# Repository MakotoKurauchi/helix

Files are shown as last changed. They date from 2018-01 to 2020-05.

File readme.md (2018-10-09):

# Helix

Helix

A compact split ortholinear keyboard.

## Documents

* Build Guide - [JP](/Doc/buildguide_jp.md), [EN](/Doc/buildguide_en.md)
* Firmware - [JP](/Doc/firmware_jp.md), [EN](/Doc/firmware_en.md)
* Usage - [JP](/Doc/usage_jp.md), [EN](/Doc/usage_en.md) 

## Tool & Data

* [PCB Data](/PCB)
* [Case Data](/Case)
* [Font Converter](/FontConverter)

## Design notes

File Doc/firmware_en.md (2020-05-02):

# Firmware

## To Simply Verify Function

It is possible to verify functionality without building using [QMK Toolbox](https://github.com/qmk/qmk_toolbox/releases).

Imgur

1. Verify that an atmega32u4 is detected
2. Download any of the firmwares below which suits the options selected, and open it in QMK Toolbox

- No options: [helix_rev2_default.hex](http://qmk.fm/compiled/helix_rev2_default.hex)
- 5-row OLED and backlight: [helix_rev2_default_oled_backlight.hex](https://raw.githubusercontent.com/MakotoKurauchi/helix/master/Hex/helix_rev2_default_oled_backlight.hex)
- 5-row OLED and underglow: [helix_rev2_default_oled_underglow.hex](https://raw.githubusercontent.com/MakotoKurauchi/helix/master/Hex/helix_rev2_default_oled_underglow.hex)
- 4-row OLED and backlight: [helix_rev2_default_4rows_oled_backlight.hex](https://raw.githubusercontent.com/MakotoKurauchi/helix/master/Hex/helix_rev2_default_4rows_oled_backlight.hex)
- 4-row OLED and underglow: [helix_rev2_default_4rows_oled_underglow.hex](https://raw.githubusercontent.com/MakotoKurauchi/helix/master/Hex/helix_rev2_default_4rows_oled_underglow.hex)
-
Imgur

1. Press the reset button on helix, and verify that it shows as "connected"
2. Immediately press flash

Imgur

If a message similar to this appears, flashing has succeeded.

Please verify that typing is possible using these firmwares.

To change the layout, use the build guide below.

## Setting up the build environment

Create the build environment according to the official guide of QMK.

https://docs.qmk.fm/#/newbs_getting_started

## Build and flash

Run the following at the root directory of the QMK folder:

    make helix:default

To flash at the same time, attach `:avrdude` to the command:

    make helix:default:avrdude

For flashing via GUI, use [QMK Toolbox](https://github.com/qmk/qmk_toolbox/releases) as described earlier.

Both halves must be flashed.

## Customize

Copy and rename the `default` folder in `/keyboards/helix/rev2/keymaps/`.
This new folder will be used from now on.

For building this new keymap, the following command will be used:

    make helix:<new keymap folder name>

## Editing the keymaps

The default keymap is stored in keymap.c. It can be edited to modify the keymap freely.

Please see [this page](https://docs.qmk.fm/#/keycodes) for a keycode reference.

Imgur

## Making the keymap 4 rows

Within the folder, change the field HELIX_ROWS rules.mk from 5 to 4.

    HELIX_ROWS = 4

## Enable RGB backlighting

In the same file, change the LED_BACK_ENABLE from no to yes.

    LED_BACK_ENABLE = yes

##  Enable RGB underglow

Again in the same file, change LED_UNDERGLOW_ENABLE from no to yes.

    LED_UNDERGLOW_ENABLE = yes

## Enable OLED display

Again in the same file, change OLED_ENABLE from no to yes.

    OLED_ENABLE = yes

### Edit font data
The font data is stored in helix/common/glcdfont.c.
This data can be edited in the following ways for modifying OLED content.

#### Using the web tool

The web tool created by [@teri_yakichan](https://twitter.com/teri_yakichan) can be used to modify the file easily.

[Helix Font Editor](https://helixfonteditor.netlify.com/)

#### Using an image editor

To use an image editor, do the following to convert text to image.

1. Take the image data from glcdfont.c and move it to a text file.
0x00, 0x00 ... 0x00
2. Use the script to convert to image
3. Edit the image
4. Use the script to convert back to text
5. Insert to glcdfont.c

An example image being edited:

Font

The following script is used for conversion.
https://github.com/MakotoKurauchi/helix/tree/master/FontConverter

Converting text to image

    $ python3 hex2img.py inHex.txt outImage

Converting image to text

    $ python3 img2hex.py inImage.bmp > outHex.txt

### Creating a font data specific to the keymap

Editing helix/common/glcdfont.c affects all keymaps. To make a font data unique to a keymap, edit the LOCAL_GLCDFONT field in rules.mk:

    LOCAL_GLCDFONT = yes

Then, rename glcdfont.c to helixfont.h and place it in the same directory as keymap.c.

## Other customization

QMK has many features. See the [docs](https://docs.qmk.fm) and others' customizations to build your own unique helix.

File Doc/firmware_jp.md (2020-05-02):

# ファームウェア

## とりあえず動作を確認したい

[QMK Toolbox](https://github.com/qmk/qmk_toolbox/releases)を使えばビルドなどの手順を踏まずにキーボードとしての動作を確認出来ます。

Imgur

1. atmega32u4 になってるか確認します
2. Helixの構成に合わせて下記のいずれかのHexファイルをダウンロードし、Openボタンでそのファイルを選択してください。

- オプション無し: [helix_rev2_default.hex](http://qmk.fm/compiled/helix_rev2_default.hex)
- 5行版 OLED & バックライト: [helix_rev2_default_oled_backlight.hex](https://raw.githubusercontent.com/MakotoKurauchi/helix/master/Hex/helix_rev2_default_oled_backlight.hex)
- 5行版 OLED & Underglow: [helix_rev2_default_oled_underglow.hex](https://raw.githubusercontent.com/MakotoKurauchi/helix/master/Hex/helix_rev2_default_oled_underglow.hex)
- 4行版 OLED & バックライト: [helix_rev2_default_4rows_oled_backlight.hex](https://raw.githubusercontent.com/MakotoKurauchi/helix/master/Hex/helix_rev2_default_4rows_oled_backlight.hex)
- 4行版 OLED & Underglow: [helix_rev2_default_4rows_oled_underglow.hex](https://raw.githubusercontent.com/MakotoKurauchi/helix/master/Hex/helix_rev2_default_4rows_oled_underglow.hex)
-
Imgur

1. Helixのリセットボタンを押し、Connected とメッセージが出るのを確認します
2. すぐにFlashボタンを押します

Imgur

このようなメッセージが出れば書き込み終了です

Helixで文字が打てるようになったでしょうか？

配列を変えたいときは次から説明するファームウェアのビルドに挑戦してみましょう。

## ビルド環境を作る

QMKの公式ガイドに従いビルド環境を作ります。

https://docs.qmk.fm/#/ja/newbs_getting_started

## ビルドと書き込み

QMKファームウェアの第一階層で以下のようにします。

    make helix:default

キーボードへの書き込みまで同時に行うには下記のように`:avrdude`を付けます。

    make helix:default:avrdude

GUIでの書き込みには冒頭で説明した[QMK Toolbox](https://github.com/qmk/qmk_toolbox/releases)が使えます。

左右のキーボードとも同様に書き込みが必要です。

## カスタマイズ

/keyboards/helix/rev2/keymaps/ にある default フォルダを複製して好きな名前にします。
以後、それを修正します。

その時のビルドコマンドは以下のようになります。

    make helix:<あなたのkeymap名>

## キーマップを変更する

デフォルトのキーマップは下記のようになっています。これは
keymap.c
を修正することで自由に変更することが出来ます。

キーコードは[リファレンス](https://docs.qmk.fm/#/keycodes)などを参照してください。

Imgur

## 4行版に対応する

キーマップ内の rules.mk にある HELIX_ROWS を 5 から 4 に変更します。

    HELIX_ROWS = 4

## RGBバックライトを有効にする

キーマップ内の rules.mk にある LED_BACK_ENABLE を no から yes に変更します。

    LED_BACK_ENABLE = yes

##  Underglow を有効にする

キーマップ内の rules.mk にある LED_UNDERGLOW_ENABLE を no から yes に変更します。

    LED_UNDERGLOW_ENABLE = yes

## OLEDを有効にする

キーマップ内の rules.mk にある OLED_ENABLE を no から yes に変更します。

    OLED_ENABLE = yes

### フォントデータのカスタマイズ
フォントデータは helix/common/glcdfont.c です。
こちらを下記のいずれかの方法で編集することでOLED表示のカスタマイズが出来ます。

#### Web Toolで編集

[@teri_yakichan](https://twitter.com/teri_yakichan) さんが作成した、ブラウザでglcdfont.cを編集するツールが便利です。

[Helix Font Editor](https://helixfonteditor.netlify.com/)

#### 画像エディタで編集

画像エディタを使いたいときは、下記の手順で一旦画像化してから編集し再度テキスト化します。

1. glcdfont.c からデータ部分のみを抜き出してテキストファイルを作る  
0x00, 0x00 ... 0x00
2. スクリプトで画像に変換する
3. 画像を修正する
4. スクリプトでテキストに戻す
5. glcdfont.c に反映させる

編集画像のイメージ

Font

スクリプトはこちらを使用します。
https://github.com/MakotoKurauchi/helix/tree/master/FontConverter

テキストから画像への変換

    $ python3 hex2img.py inHex.txt outImage

画像からテキストへの変換

    $ python3 img2hex.py inImage.bmp > outHex.txt

### キーマップ毎にフォントデータを用意する

helix/common/glcdfont.c を修正してしまうと全てのキーマップに影響が出ます。キーマップ独自のフォントファイルを用意したい時は、まず下記のようにキーマップ内の rules.mk にある LOCAL_GLCDFONT を no から yes に変更します。

    LOCAL_GLCDFONT = yes

次に glcdfont.c を helixfont.h とリネームして keymap.c と同じ階層に複製します。

## それ以外のカスタマイズ

QMKは沢山の機能があります。[リファレンス](https://docs.qmk.fm)や他の人のカスタマイズを参考にして自分だけの最高のHelixを作って下さいね！

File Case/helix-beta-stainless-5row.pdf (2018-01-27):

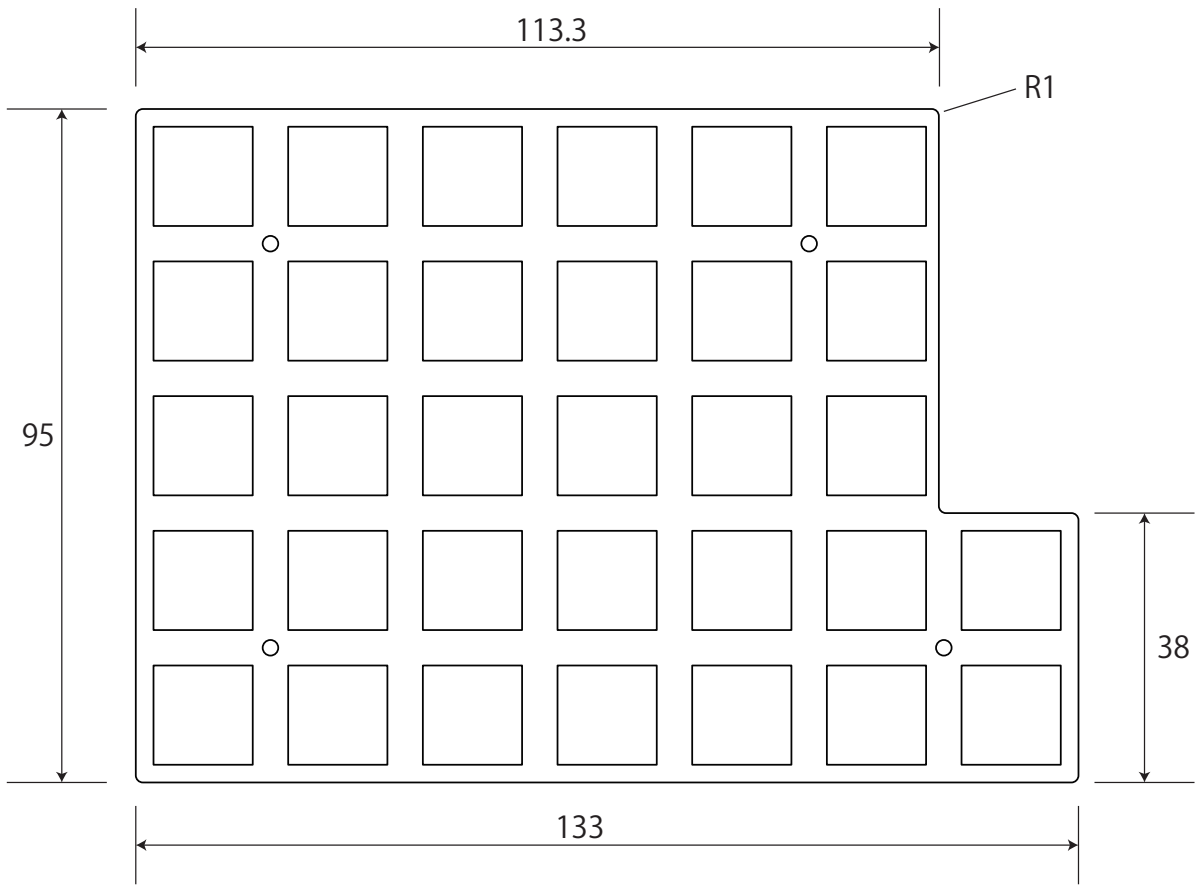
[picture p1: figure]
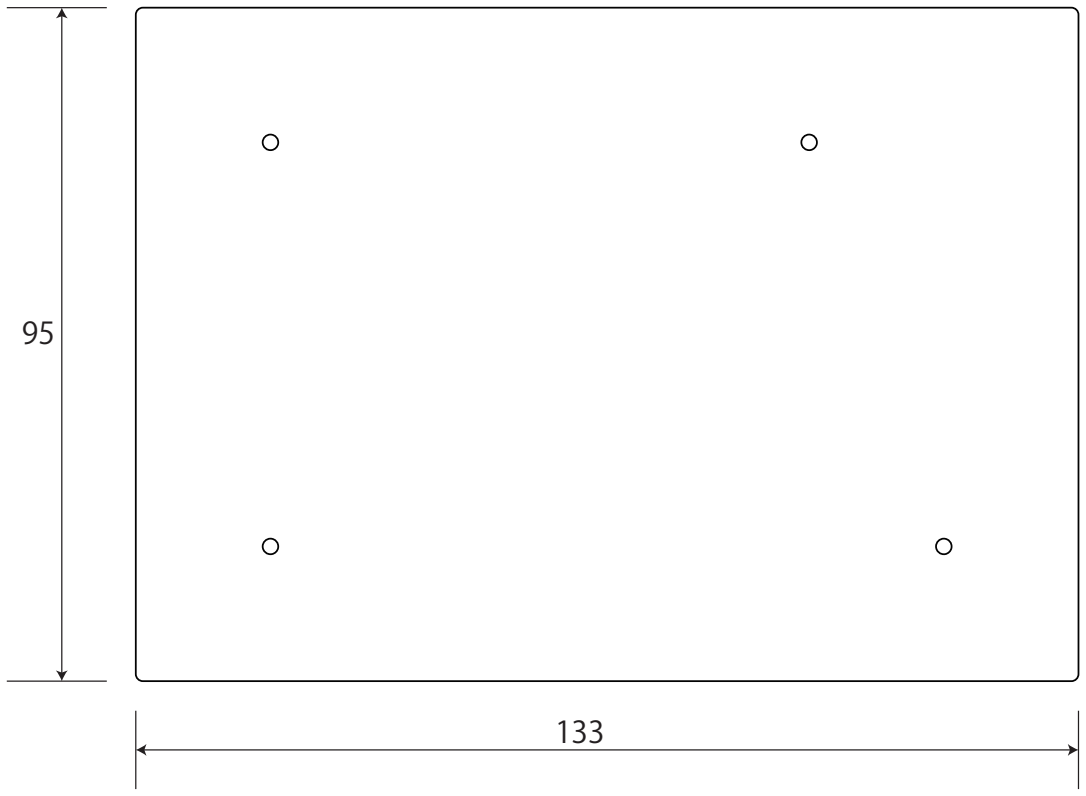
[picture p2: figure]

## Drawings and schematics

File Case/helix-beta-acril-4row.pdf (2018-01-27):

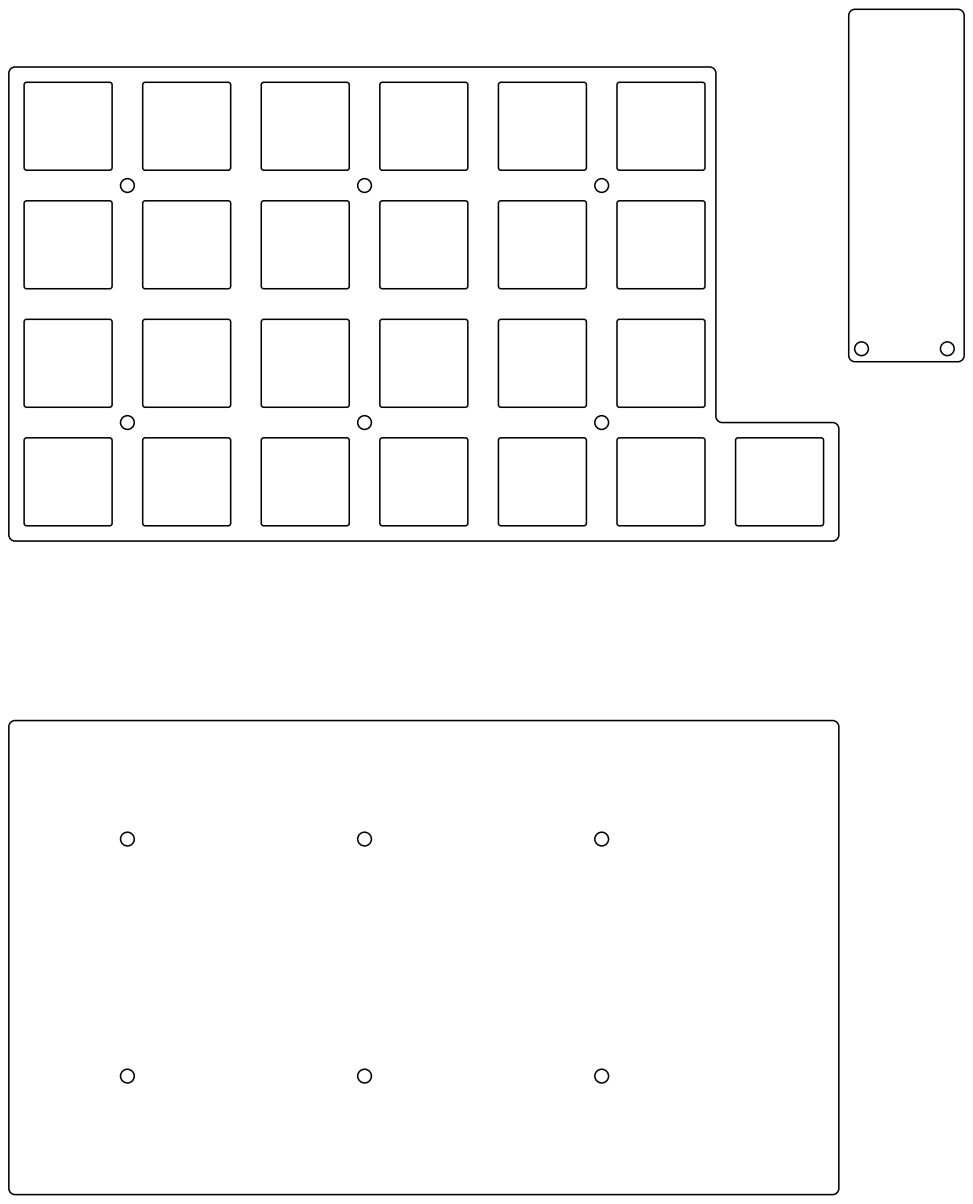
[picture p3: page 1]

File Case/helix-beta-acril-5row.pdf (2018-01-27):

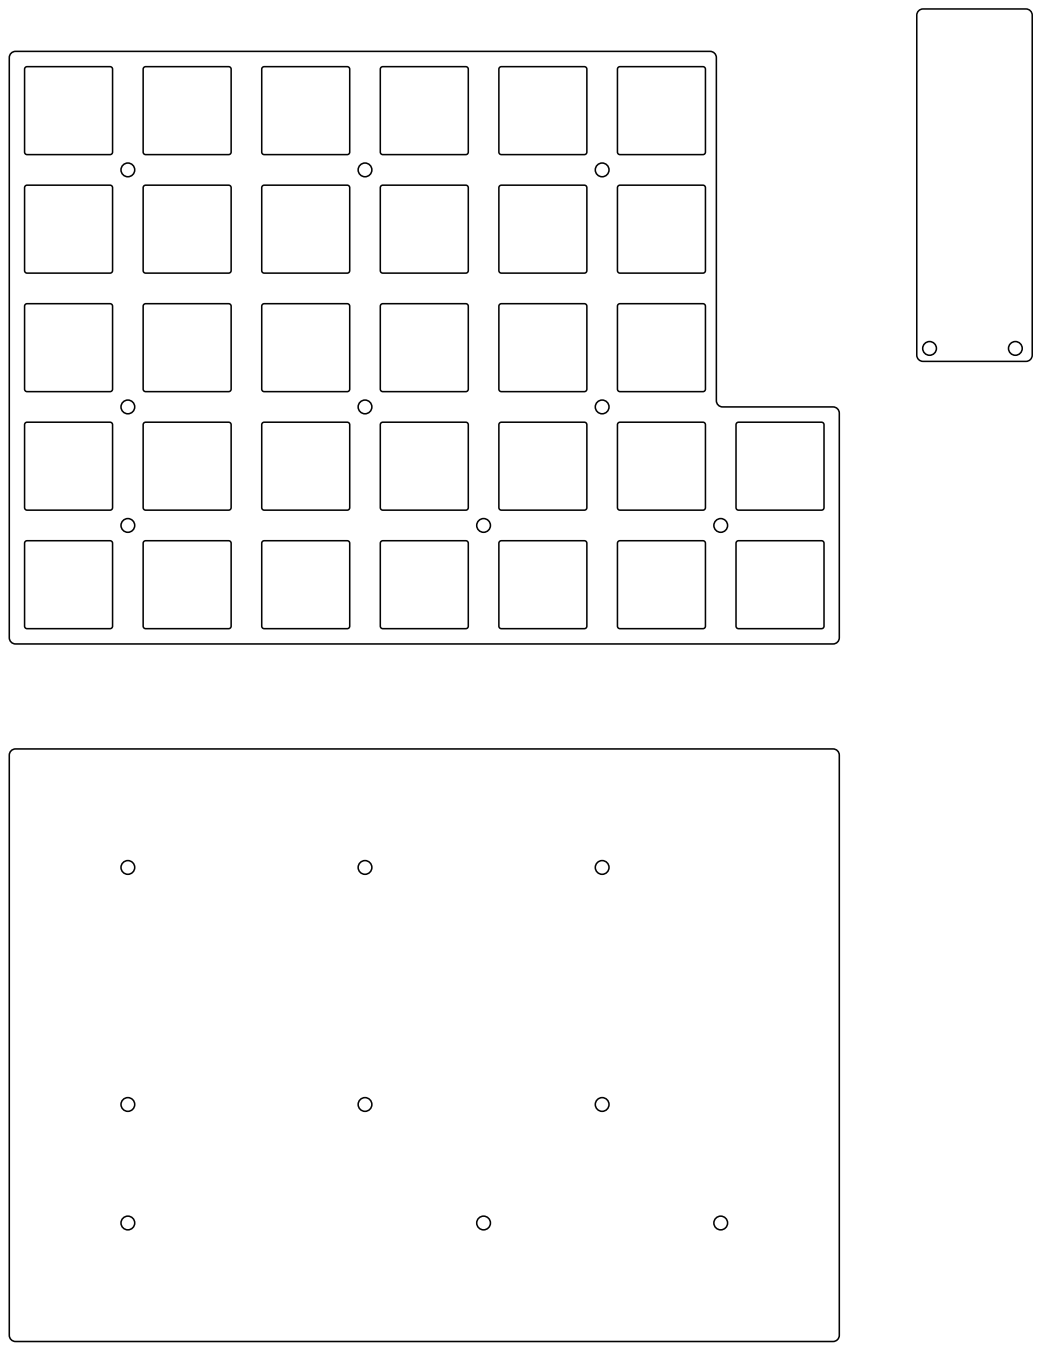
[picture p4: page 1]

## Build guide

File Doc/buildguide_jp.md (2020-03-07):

# Helixベータ ビルドガイド

## 部品

下記は1つ作るのに必要な部品の数です。両手分を作るには2セット必要です。

| 名前 | 数 | 備考 |
| ---- | ---- | --- |
| PCB | 1枚 | |
| Pro Micro | 1個 | |
| TRRSジャック | 1個 | |
| タクトスイッチ | 1個 | |
| スプリングピンヘッダ 12P | 2個 | 通常のピンヘッダでも可 |
| プレート（アクリルかステンレス） | 1セット| |
| 保護プレート | 1枚 | |
| M2スペーサー 4mm | 6個 | ロープロファイルスイッチ用 |
| M2スペーサー 7mm | 6個 | MX互換スイッチ用 |
| M2スペーサー 8mm | 2個 | |
| M2ネジ 3mm| 14個 | |
| M2低頭ネジ 5mm| 2個 | |
| ゴム足 | 6個 |  |
| ダイオード | 32個 | ロープロファイルスイッチを使用する場合はSMDのダイオードが必要です。 |
| キースイッチ | 32個 | KalihロープロファイルあるいはMX互換 |
| キーキャップ | 32個 | キースイッチと互換があるもの |
| 3.5mmオーディオケーブル | 左右合わせて1本 | 左右のキーボード接続用 |
| micro USBケーブル | 左右あわせて1本 | |
| 絶縁シート | 1枚 | ステンレスプレート用（オプション）|
| LEDストリップ（WS2812B 6個付き） | 1個 | Underglow用（オプション） |
| SK6812mini | 32個 | バックライト用（オプション） |
| OLEDモジュール | 1個 | OLED用（オプション） |
| ピンソケット 4P | 1個 | OLED用（オプション） |
| ピンヘッダ 4P | 1個 | OLED用（オプション） |

## 必要な道具

| 名前 | 備考 |
| ---- | ---- |
| はんだごて | バックライトLEDを使用する場合は調温出来るもの |
| 糸ハンダ | 0.8mm程度のものを推奨 |
| ピンセット | チップ部品実装時 |

## 構成の選択
制作を始める前にどのような構成にするか決めておく必要があります。

### 行数の選択（５行または４行）
PCBを切断することによってデフォルトの５行から４行へ変更することができます。

### LEDの選択（Underglowかバックライト）
テープLEDを使用したUnderglowか、チップLEDを使用するバックライトを選択します。

## 組み立て方

以降は左手用で説明します。右手用はPCBを反転して下さい。

Imgur

__一度全ての工程を読み、理解してから作業を進めることをお勧めします。__

### PCBの準備

オプションのOLEDモジュールを使用するときはPCBにジャンパが必要になります。
左右ともに**上面側**の４箇所をジャンパします。
（両面をジャンパしてはいけません）

Imgur

### パーツ実装

#### ダイオード

リードタイプ、チップタイプ共にPCBの**下面側**から実装します。

ダイオードには向きがあるので注意してください。
シルクが見えなくなっているところがありますが、全て同じ方向なので他に合わせてください。

Imgur

Imgur

#### バックライトLED（オプション）

バックライト用のチップLEDはPCBの**下面側**から実装します。向きに注意して穴に入れてください。裏から見て、一番大きいパッドとシルクの○が同じ位置になります。

シルクが見えなくなっているところがありますが、同じ行は同じ向きですので見えるところを参考にしてください。また、**行ごとに向きが変わるので注意してください**。

調温半田ごてを使い、約220℃ではんだ付けします。__温度が高いとLEDが壊れますのでご注意ください__。

Imgur

Imgur

1行分まとめてLEDを並べて一番大きいパッドだけ仮で半田付けしてから、残りの部分をはんだ付けすると、効率よくつけられます。

#### TRRSジャック

シルクにしたがって上面から実装してください。

Imgur

#### リセットスイッチ

タクトスイッチを上面から実装してください。

Imgur

#### Pro Micro

スプリングピンヘッダをPro Microに半田付けします。Pro Microの裏面（平らな方）が上になるようにします。

Imgur

スプリングピンヘッダには推奨する向きがあります。

Imgur

小さい窓がPro Micro寄りになります。
また、実装時には二本ともに小さい窓が同じ方向を向くようにしてください。

Imgur

Imgur

※向きを間違えたり、はんだ付けする前に強い力がかかるとピンが外れますので注意してください。また、足が折れ曲りやすいので抜き差しするときには注意して扱ってください。

裏面を上にしてPCBの白枠線内のスルーホールに取り付けてください。はんだ付けしなくても固定されます。

Imgur

#### OLEDモジュール（オプション）

ピンソケットを上面に実装し、ピンヘッダをOLEDモジュールに半田付けします。
そしてPro Microの上に被せるようにしてピンソケットに差し込みます。

Imgur

Imgur

#### Underglow用テープLED（オプション）

向きに注意して裏面に直接実装するか配線材を使って実装してください。

Imgur

#### キースイッチ

マウントプレートを挟んでPCBに実装します。
狭いところは隣のパッドにブリッジしないよう気をつけて下さい。

Imgur

※ここまで来たら一旦[ファームウェア](firmware_jp.md)を書き込み、動作確認をした方が良いでしょう。

### 最終組み立て

8mmのスペーサーを2本、PCB上面にネジ止めします。

Imgur

ロープロスイッチは4mm、MXキースイッチは7mmのスペーサーを使い、PCBをサンドイッチするように底面用のプレートをネジ止めします。

Imgur

保護プレートを8mmのスペーサーに低頭ネジを使ってネジ止めします。

Imgur

ゴム足を底面に貼ります。

Imgur

完成です。

Imgur

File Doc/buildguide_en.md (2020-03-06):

# Helix Beta Build Guide

## Parts

The list below is for one half. To build both halves, you will need two sets of these parts.

| Name | Quantity | Notes |
| ---- | ---- | --- |
| PCB | 1 | |
| Pro Micro | 1 | |
| TRRS Jack | 1 | |
| Tactile Switch | 1 | |
| Spring-loaded pin headers 12-pin | 2 | Regular headers will also work |
| Plate (Acrylic or Stainless) | 1 set | |
| Display Cover Plate | 1 | |
| M2 Spacer 4mm | 6 | For low-profile switches |
| M2 Spacer 7mm | 6 | For MX-style switches |
| M2 Spacer 8mm | 2 | |
| M2 Screw 3mm| 14 | |
| M2 Low Profile Screw 5mm| 2 | |
| Rubber Bump-Ons | 6 |  |
| Diodes | 32 | SMD diodes are required for low-profile switches. |
| Keyswitches | 32 | Either Cherry MX or Kailh Low-Profile compatible |
| Keycaps | 32 | Whichever caps suit the switches |
| 3.5mm Aux Cable | 1 | For the split connection |
| MicroUSB Cable | 1 | |
| Insulating Sheet | 1 | For stainless steel plates (Optional) |
| WS2812B Strip (6 LEDs) | 1 | For underglow (Optional) |
| SK6812mini | 32 | For backlight (Optional) |
| OLED Module | 1 | For OLED display (Optional) |
| Socket, 4-Pin | 1 | For OLED display (Optional) |
| Headers, 4-Pin | 1 | For OLED display (Optional) |

## Necessary Tools

| Name | Notes |
| ---- | ---- |
| Soldering Iron | If using backlight LEDs, it must be temperature-controllable. |
| Thin solder | ~0.8mm diameter recommended |
| Tweezers | For SMD part assembly |

## Selecting Options
Before beginning assembly, it will be necessary to decide on the options for the build.

### Row Quantity (5 or 4)
By breaking away the bottom row, you can select the row quantity.

### LED Selection (Underglow or Backlight)
Either the per-key backlight or below-PCB underglow may be selected.

## Building the Helix

The guide will focus on the left half. For the right, simply flip the PCB.

Imgur

__It is strongly recommended to read the ENTIRE build guide first before beginning work.__

### Preparing the PCB

If installing the optional OLED display, jumpers must be connected.
Please solder the four jumpers on the __upper side__ of the PCB on both halves.
(Do not solder jumpers on both the front and rear.)

Imgur

### Installing Parts

#### Diodes

Install diodes onto the __bottom__, whether through-hole or surface mount.  Note: if using choc low profile switches surface mount diodes are recommended as through hole diode legs would need to be flush on the top of the board to allow the top plate to sit correctly.  See issue [22](https://github.com/MakotoKurauchi/helix/issues/22) for details and work arounds.

Make sure all diodes are installed in the correct orientation.
Even when the silk label is invisible, all diodes face the same orientation.

Imgur

Imgur

#### Backlight LED (Optional)

Backlight LEDs are installed from the **bottom** of the PCB. Verify the orientation of the LEDs when installing - the largest pad should align with the corner marked with the circle on the silkscreen layer.

There are some places where this silkscreen is invisible; however, all LEDs of each row face the same orientation. However, **not all rows share the same orientation** (they switch orientation by 180 degrees each row).

Using a variable temperature soldering iron, solder the LEDs into place at roughly 220C (428F). __Overheating the LEDs will destroy the LEDs.__

Imgur

Imgur

An efficient method is to solder the largest pads on the entire row, then to do the rest of the pads.

#### TRRS Jack

Install from the topside following the silkscreen.

Imgur

#### Reset Switch

Install from the topside as marked by silkscreen.

Imgur

#### Pro Micro

Solder the spring loaded header to the pro micro, making sure that the bottom side faces upwards.

Imgur

The recommended orientation is the following.

Imgur

The smaller windows should be on the Pro Micro side.
Also, install so both sets of headers have the small windows facing the same orientation.

Imgur

Imgur

Installing in the wrong orientation or applying significant force before soldering will lead to the pins ejecting. Also, the legs are easily bent; please take care when inserting and removing the Pro Micro from the PCB.

With the bottom side up, insert the header-loaded Pro Micro onto the through-hole pads. Even without soldering, it should lock into place.

Imgur

#### OLED Module (Optional)

Install sockets on the topside, and solder the headers onto the OLED module.
Install the OLED module so it covers the Pro Micro below.

Imgur

Imgur

#### RGB Underglow Strip

After verifying orientation, either solder into place or solder using jumper wires.

Imgur

#### Switches

Install switches to the plate, then to the PCB, and solder.
Be careful of solder bridges when other parts are close by.

Imgur

* At this point, it is recommended to flash the [firmware](firmware_en.md), and to verify that everything functions properly.

### Final Assembly

Install two 8mm standoffs on the topside, and screw into place.

Imgur

Using 4mm standoffs on low-profile and 7mm for MX, secure the bottom plate into place as to sandwich the PCB.

Imgur

Install the display-protecting plate using the low-profile screws.

Imgur

Install bump-ons.

Imgur

The build is complete.

Imgur

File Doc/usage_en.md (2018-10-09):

# Usage Guide

The usage of Helix is described using the default keymap.

## Connection between the halves

Either a TRS or TRRS 3.5mm aux cable is used.  
(Even with LEDs or OLEDs, a TRS cable works fine.)

* To avoid damage, always connect the aux cable __first__ and USB cable after the halves are connected.

Imgur

## Layers

The Helix obviously does not have enough keys compared to a typical keyboard.  
The keymap has multiple layers, moving extra keys to different layers.

|Priority|Layer ID|Layer Name|Contents|
| ---- | ---- | --- | --- |
|High|5|Adjust|Function Keys|
||4|Raise|Symbols (Pink)|
||3|Lower|Symbols (Blue)|
||2|Dvorak|Dvorak layout|
||1|Colemak|Colemak layout|
|Low|0|Qwerty|Qwerty layout (Base)|

Usually hidden, the layers above the base layer appear by using the layer adjust keys. Wherever keys overlap, the keys with higher priority replace the keys below it.

For example, here is an example of "Raise" and "Lower" overlaid above the base.
For example, holding the pink raiser key when pressing `a` registers the F1 key.

Imgur

Next, here is the adjust layer overlaid onto base.  
For example, pressing `q` while holding Adjust sends the reset keycode, making the keyboard enter its bootloader (Same as pressing the reset button).

Imgur

On the default keymap, pressing Raise and Lower together registers Adjust.

## LED Control

To control the LED backlighting and underglow, the keys on the adjust layer are used.

|Command|Default Layout|Keycode|
| ---- | ---- | --- |
|On/Off|Adjust + ,|RGB_TOG|
|Mode|Adjust + Left|RGB_SMOD|
|Reset|Adjust + w|RGBRST|
|Hue Increase|Adjust + .|RGB_HUI|
|Hue Decrease|Adjust + Down|RGB_HUD|
|Saturation Increase|Adjust + /|RGB_SAI|
|Saturation Decrease|Adjust + Up|RGB_SAD|
|Value Increase|Adjust + Enter|RGB_VAI|
|Value Decrease|Adjust + Right|RGB_VAD|

## Switching between Mac and Windows mode

In Mac mode, the EISU and Kana keys function as English/Numerics and Kana input keys respectively.

In Windows mode, the EISU and Kana keys both function as Alt + ` (Japanese IME switcher).
Also, <font color="Red">the Alt and GUI keys are swapped.</font>。

The current mode is displayed on the OLED display.

|Command|Default Layout|Keycode|
| ---- | ---- | --- |
|Mac Mode|Adjust + g|AG_NORM|
|Windows Mode|Adjust + h|AG_SWAP|

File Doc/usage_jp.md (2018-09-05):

# 使い方

Helixの使い方をデフォルトキーマップで説明します。

## 左右の接続

左右の接続には3極（TRS）もしくは4極（TRRS）のステレオオーディオミニプラグを使用します。  
（LEDやOLEDを使用する場合でも3極で問題ありません）

※故障する恐れがありますのでUSBケーブルを繋げたままでの挿抜はしないでください。

Imgur

## レイヤー

Helixは通常のキーボードと比較して明らかにキーの数が足りません。  
キーマップはレイヤーを重ねた多層構造になっており、収まらないキーやHelixの設定を変える機能キーは別のレイヤーに入っています。

|優先順位|レイヤー番号|レイヤー名|内容|
| ---- | ---- | --- | --- |
|高い|5|Adjust|機能キー|
||4|Raise|記号類（ピンク）|
||3|Lower|記号類（ブルー）|
||2|Dvorak|Dvorak配列|
||1|Colemak|Colemak配列|
|低い|0|Qwerty|QWERTY配列（ベース）|

ベースレイヤー以外は普段は隠れていますが、対応するレイヤーキーを押すことで現在の配列の上にそのレイヤーが現れます。重なったところは、レイヤー番号が大きいほうが優先順位が高くなりますので、キーコードが変わることになります。

具体例をあげると、RaiseとLowerをQwertyに重ねたのが下の画像です。  
例えばピンクのRaiserキーを押しながらaを押すと、F1キーなります。

Imgur

次にAdjustとQwertyを重ねたのが下の画像です。  
例えばAdjustを押しながらqを押すとキーボードがリセットされ、書き込みモードになります。（リセットスイッチを押したときと同じ状態）

Imgur

また、デフォルトキーマップでは、Lower + Raiseの同時押しはAdjustとなるようにしています。

## LEDコントロール

バックライトやUnderglowをコントロールするにはAdjustレイヤーにある機能キーを使います。

|コマンド|デフォルトレイアウト|コード|
| ---- | ---- | --- |
|オン／オフ|Adjust + ,|RGB_TOG|
|モード|Adjust + Left|RGB_SMOD|
|リセット|Adjust + w|RGBRST|
|色相 +|Adjust + .|RGB_HUI|
|色相 -|Adjust + Down|RGB_HUD|
|彩度 +|Adjust + /|RGB_SAI|
|彩度 -|Adjust + Up|RGB_SAD|
|明度 +|Adjust + Enter|RGB_VAI|
|明度 -|Adjust + Right|RGB_VAD|

## MacモードとWinモードの切り替え

MacモードはEISUキーとKANAキーがそれぞれ英数キーとかなキーとして入力されます。

WinモードはEISUキーとKANAキーが共に Alt + `（日本語IMEの切り替え）として入力されます。  
また、<font color="Red">AltキーとGUIキーが入れ替わります</font>。

現在のモードはOLEDにアイコンとして表示されます。

|コマンド|デフォルトレイアウト|コード|
| ---- | ---- | --- |
|Macモード|Adjust + g|AG_NORM|
|Winモード|Adjust + h|AG_SWAP|

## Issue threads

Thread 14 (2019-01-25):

A 75% keyboard would be amazing.

zandegran, 2019-01-25:
Most of the European languages have additional characters and a 75% keyboard would have enough keys to accommodate dedicated keys for those, without having to change the keyboard layout. Another use case can be developers can have dedicated keys for {}() to make life lot easier.

Even without these a 75% keyboard would be a nice addition.

culturalsnow, 2019-01-26:
Can see your point, but not sure if this counts as an issue for the Helix keyboard itself?

theAkito, 2020-01-22:
If the Helix would be a full-size keyboard like e.g. the BFO-9000, I would immediately start building it. The problem is all the hype about these tiny keyboards...

@culturalsnow Yes, it is an issue with the Helix keyboard, because it is too small. If the PCB would be bigger, then you could still break off rows that you don't need. Whereas if the PCB is too small in the first place, then you hardly can attach new rows...

MakotoKurauchi, 2020-01-28:
This is not a Helix keyboard issue.
I close this issue.

zeljkot, 2020-05-25:
7 x 7 (+1) Helix would be great for both ISO layout and programming.

Closed 2020-01-28.

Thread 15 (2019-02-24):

Kailh Hot Swappable sockets?

mr-ubik, 2019-02-24:
Any plans on upgrading the PCB schematics with Kailh Hot Swappable sockets?

MakotoKurauchi, 2020-01-28:
I am considering.

Closed 2020-01-28.

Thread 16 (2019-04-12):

Case Measurements

Vesyrak, 2019-04-12:
Hey,

Would it be possible to make the exact measurements of the holes, switch openings and distance between them available?

Thanks!

ccadic, 2019-04-28:
Yes.
Which PCB are you talking about ?
I will make the measuremernts

Le ven. 12 avr. 2019 à 15:28, Vesyrak <notifications@github.com> a écrit :

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

--
** Dr Philippe Cadic **
Ce message ainsi que toutes les pièces jointes (ci-après le message) sont
établis à l’intention exclusive de son ou ses destinataires. Si vous
recevez ce message par erreur, merci de le détruire et d’en avertir
immédiatement l’expéditeur par courriel.
Toute utilisation de l’adresse électronique de l’émetteur à des fins
publicitaires, toute utilisation de ce message à des fins non conformes à
sa destination, toute diffusion ou toute publication, totale ou partielle,
est interdite, sauf autorisation expresse.
Les communications sur Internet n’étant pas sécurisées, l'auteur décline
toute responsabilité en cas de modification du message et de ses pièces
jointes.

Vesyrak, 2019-04-28:
Hey,

Yes, I was thinking of the measurements for the 5 row stainless steel case, but I figured out they can be read using Adobe Illustrator.

Thanks anyway!

ccadic, 2019-04-28:
Godd idea. What s the pcb you are talking about ? I made so many

Le dim. 28 avr. 2019 à 13:03, Vesyrak <notifications@github.com> a écrit :

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

Vesyrak, 2019-04-28:
Hey,
Just the Helix 5 rows one

Cheers

ccadic, 2019-04-28:
Do you have the URL or photo . I do not see which board you are talking
about. I have made over 50 boards

Le dim. 28 avr. 2019 à 16:13, Vesyrak <notifications@github.com> a écrit :

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

mtei, 2019-04-28:
Hi,
Have you already seen the following data?

https://github.com/MakotoKurauchi/helix/tree/master/Case

Vesyrak, 2019-04-28:
@ccadic
I am talking about the board that is defined in this repository, as I opened the issue here.

@mtei
Yes I have, and my problem is solved

I really appreciate the help, but the issue is already fixed

Closed 2019-04-28.

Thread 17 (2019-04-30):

three switches on row 4 activate entire column

littlekeyboards, 2019-04-30:
recently made pcbs from the provided kicad files and three keys on row 4 of the pcb activate the entire column. if using the pcb as left side, Z, X, and B activate the whole column

Closed 2019-05-03.

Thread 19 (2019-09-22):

Removing LED cutouts

joric, 2019-09-22:
What was the reason behind those LED cutouts? Are they for reverse mount LEDs? I was under impression there are no reverse mount adressable LEDS. Why did you make those cutouts? Are they for compatibility with non-RGB switches only? The board will be better without cutouts and will support SMD reflow process without soldering each LED with individual solder bridges. Was there even a real reason?

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

joric, 2019-09-23:
OK we've had a discussion on Discord, key points:

1. JP community values the process of hand-crafting keyboards from the bare PCB up rather than buying a near-complete kit and simply throwing in switches. As such, the helix and derivatives were all designed without PCBA as a goal. (c) ai03

2. There are enthusiast switches that have RGB properties without having the RGB cutout, such as Zeals and generally all switches with transparent casing.

3) Choc switches also won't be compatible (communuty loves choc switches). They have RGB cutouts, but, like, smaller, for 2525 LEDs or something so they won't sit flush as well.

4) There are proper reverse mounted switches https://yushakobo.jp/shop/a0800rl-10/ but they're not adressable so this keypoint does nothing.

The general idea was, community doesn't mind handsoldering and hates PCBA so reverse mounted SK6812 is the "ideal" option. Also YOU CAN FORK.

Closing for now.

Closed 2019-09-23.

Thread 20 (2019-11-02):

Keyboard not detected by QMK Toolbox

lacymorrow, 2019-11-02:
Hi, I didn't know where else to post this. I'm not getting any output from the keyboard when plugging the Pro Micro into the PC.

If I remove the Pro Micro from the keyboard, it is detected by QMK toolbox.

Do you have any ideas of things I can test to try to get this keyboard working?

I've posted some photos of the work-in-progress here: https://imgur.com/a/3gnFJrw

Any help is greatly appreciated, I'm stuck and don't know what else to try!

mrwspace, 2020-01-16:
Do you get any lights at all on the micro? It seems to me that there is a short on the board.

lacymorrow, 2020-01-16:
It does seem like that is the case, I ended up getting a second PCB and was able to get it working.

mrwspace, 2020-01-17:
>FWIW I removed every component from the board, cleaned very well with a solder sucker and wick, and still was experiencing issues.

That seems odd. I would expect to see it working if no parts are installed on the PCB. Do you still have the LEDs on the PCB? If you solder any of the LEDs in the wrong orientation, this could cause your board to short. Probably the easiest way to check it out would be with a digital multimeter.

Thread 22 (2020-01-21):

Build Instructions question regarding appropriate Diode to use for kailh choc switches.

floodedcodeboy, 2020-01-21:
Hi @MakotoKurauchi,

Just wanted to say thank you for designing such a beautiful looking board.

I wanted to ask if you think you could use through-hole diodes in place of SMD diodes and still be able to complete this build with kailh choc switches.

Thank you.

jpconstantineau, 2020-01-21:
The potential problem with through-hole diodes is the fact that even when
you cut the legs very short, they could still touch the top plate.  I have
had problems with using through-hole diodes on my ErgotravelLight (choc
Switches) and even if the diodes were at the bottom of the PCB, the cut
legs (and small solder "mountain") was still too high and they contacted
the top plate.  With SMD diodes on the bottom side, you do not have this
source of problem possible.

I don't know the specifics for the helix but I would suspect that a similar
problem would be possible.

On Tue, 21 Jan 2020 at 10:42, Jacob Gabriel <notifications@github.com>
wrote:

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

--
Pierre

floodedcodeboy, 2020-01-25:
@jpconstantineau So i went ahead with the through hole anyways and you're quite right ,  I now have an issue where the top plate is raised by these tiny solder mountains. and the legs for the chocs can't quite make it all the way through the holes... so i'm left with a few options i guess:

* buy new pcb's and SMD diodes (a part number would be handy here)
* buy SMD Diodes and remove the soldered through hole diodes
* use cherry switches
* get a thinner plate cut

thoughts and suggestions welcome.

jpconstantineau, 2020-01-25:
If you have copper wick or a solder sucker, you could unsolder those little
mountains and cut the wires very close to the pcb. As long as there is
solder between the legs and the sides of the holes, you should have
electrical contact. Alternately, you could pull the diodes out slightly
until the mountains gets pulled in and are almost flush with the pcb. It’s
not as nice but sure is the fastest.

On Sat, Jan 25, 2020 at 9:58 AM Jacob Gabriel <notifications@github.com>
wrote:

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
--
Pierre

N6UDP, 2020-03-06:
this should probably be added to the docs. I ran into this and went with a thinner plate which is working so far...

georgwacker, 2020-04-29:
I have a couple of questions regarding diodes with kailh choc:

- if I don't use a top plate, can I solder through-hole / smd diodes on the top side?
- for SMD diodes, do I want 1N4148 in SOD-123 or SOD-323 package?

mtei, 2020-04-29:
FYI:

I think it would be okay to solder it to the top side.

I used the SOD-123.

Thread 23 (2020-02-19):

Both Pro Micros are sharing the same RX pin

udifreeze, 2020-02-19:
From a quick look on the PCB layout it seems like both Pro Micros are connected together using the TRS cable by pin number two (The RX pin of the serial port).
If it's true then the right (slave) side won't be able to send data to the left (master) side.

mtei, 2020-02-20:
Helix is working correctly. No problem.

Because Helix software doesn't use USART in Atmega32u4.

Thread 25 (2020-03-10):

clean-up firmware build variation

mtei, 2020-03-10:
去年10月の https://github.com/MakotoKurauchi/qmk_firmware/pull/20 で、Helix のファームウェアのビルド時の指定オプションが、ビルド結果のバイナリファイル名に反映するようにしました。
半年近く運用してみての経験に基づいて、今後どうしたほうがより良いのか再検討を要すると思われます。

mtei, 2020-03-10:
## 現状どうなっているか

以下のようになっています。
```
% make list-keyboards | tr ' ' '\n' | grep helix
helix
helix/pico
helix/pico/back
helix/pico/sc
helix/pico/sc/back
helix/pico/sc/under
helix/pico/under
helix/rev1
helix/rev2
helix/rev2/back
helix/rev2/back/oled
helix/rev2/oled
helix/rev2/oled/back
helix/rev2/oled/under
helix/rev2/sc
helix/rev2/sc/back
helix/rev2/sc/oled
helix/rev2/sc/oledback
helix/rev2/sc/oledunder
helix/rev2/sc/under
helix/rev2/under
helix/rev2/under/oled
```

mtei, 2020-03-10:
## 上のリストをみやすく整理すると
### Helix のオリジナルコード

#### Helix alpha
 * helix/rev1

#### Helix Pico
 * helix/pico
 * helix/pico/back
 * helix/pico/under

#### Helix
 * helix　(=helix/rev2)
 * helix/rev2/back
 * helix/rev2/back/oled
 * helix/rev2/oled
 * helix/rev2/oled/back
 * helix/rev2/oled/under
 * helix/rev2/under
 * helix/rev2/under/oled

### split_common のコードを使ったバリエーション
split_common では、現状のオリジナルコードの機能の一部が実現できていませんが、ゆくゆくは移行を迫られそうです。

#### Helix Pico on split_common
 * helix/pico/sc
 * helix/pico/sc/back
 * helix/pico/sc/under

#### Helix on split_common
 * helix/rev2/sc
 * helix/rev2/sc/back
 * helix/rev2/sc/oled
 * helix/rev2/sc/oledback
 * helix/rev2/sc/oledunder
 * helix/rev2/sc/under

mtei, 2020-03-10:
split_common を指定するバリエーションは実験的意味合いが強いですし、将来 split_common に完全移行したとしら、その時には指定することの意味を失うので今キーボードリストに現れる必要はないのかもしれません。

qmk configurator 上では、split_common 使用の指定はできなくして、コマンドラインからのビルドの場合のみ、以下のように指定できればいいのかもしれません。

```shell
$ make HELIX=sc helix:keymap_name
```

そうすると、リストに現れるバリエーションが一気に半減します。

mtei, 2020-03-10:
split_common の指定を少しだけのこす案もありえます。
split_common を指定した時は全部入り（back, oled) と割り切ってしまい以下のようにします。

#### Helix alpha
 * helix/rev1

#### Helix Pico
 * helix/pico
 * helix/pico/back
 * helix/pico/under

#### Helix
 * helix　(=helix/rev2)
 * helix/rev2/back
 * helix/rev2/back/oled
 * helix/rev2/under
 * helix/rev2/under/oled
 * helix/rev2/oled

### split_common のコードを使ったバリエーション

 * helix/pico/split_common (back 入り)
 * helix/rev2/split_common. (back, oled 入り)

mtei, 2020-03-10:
上の案にさらに、現在の Helix キットに必ず OLED が同梱されていることを考慮して、OLED なしのバリエーションを省くと

#### Helix alpha
 * helix/rev1

#### Helix Pico
 * helix/pico
 * helix/pico/back
 * helix/pico/under

#### Helix
 * helix　(=helix/rev2) (oled付き)
 * helix/rev2/back (oled付き)
 * helix/rev2/under (oled付き)

### split_common のコードを使ったバリエーション

 * helix/pico/split_common (back 入り)
 * helix/rev2/split_common. (back, oled 入り)

MakotoKurauchi, 2020-03-11:
ご提案ありがとうございます。
たしかに現在は qmk configurator に多数のビルドが出てしまい、どれを選べが良いか分かりにくくなっています。

また、現在のところ split_common を使う必要が無いので出てこない方が良さそうです。

私としては変更案その3に加え、split_commonが出てこない形が良いのではないかと思います。

mtei, 2020-03-13:
ご要望の通り、split_common を現れない形で変更をやったのですが、作業中に一つ気がついたことがあります。

qmk_firmware では、プルリクがなされると、チェックの一環として全キーボードの default キーマップのビルドが行われます。
もし、Helix の split_common の実装を見えなくしてしまうとこのチェックが行われなくなります。

split_commonの実装が満足なものになった暁には、Helix も移行することになると思うのですが、そうなるまでの間に split_commonにHelixでコンパイルできない変更を入れて欲しくはないのでチェックを有効にする為、split_common をリストに現れるようにしておいたほうが良いと思います。

いかがでしょうか。

MakotoKurauchi, 2020-03-13:
なるほど。
それではsplit_commonも入れましょう。

Closed 2020-04-02.

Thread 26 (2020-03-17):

Issues with QMK configurator when compiling Helix firmware.

Gazza2000, 2020-03-17:
When compiling firmware on QMK configurator, repeated errors occur with Helix builds. This prevents the firmware from being downloaded. The following is the error reported in the command window:

` |
 | .build/obj_helix_rev2_back_oled_default_583be4a/keyboards/helix/rev2/rev2.o: In function `matrix_init_kb':
 | /qmk_compiler/qmk_firmware/keyboards/helix/rev2/rev2.c:25: undefined reference to `is_helix_master'
 | collect2: error: ld returned 1 exit status
 |
makek:300: .build/helix_rev2_back_oled_default_583be4a.elf] Error 1
make: *** akefile:579: helix/rev2/back/oled:default_583be4a] Error 1
 ake finished with errors
 `

mtei, 2020-03-18:
Known issue.

If I only need to fix the Helix code, I can fix it right away, but unfortunately I need to change the qmk core and it will take some time.

Mandydeth, 2020-08-15:
Does this mean there is currently no way to flash a custom keymap?

amezdraven, 2020-08-16:
There is but you have to build your keymap by hand in something like notepad++ or such then compile with msys2 or linux terminal.

Mandydeth, 2020-08-16:
> There is but you have to build your keymap by hand in something like notepad++ or such then compile with msys2 or linux terminal.

I posted another thread above, but I found msys2 generated the same/similar errors. I was able to compile successfully on Linux, with the caveat being that using a .json file when compiling would not allow oled/back lighting to function, whereas building my own keymap did not.

mtei, 2020-12-11:
I made a workaround for the compile error on QMK configurator.

Currently the following four targets are compilable.
* helix/pico/qmk_conf
* helix/rev2/qmk_conf
* helix/rev3_4rows
* helix/rev3_5rows

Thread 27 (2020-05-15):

Pro micro completely unrecognised by windows machine.

Gazza2000, 2020-05-15:
Hi, I recently was able to flash my Helix halves with LED testing firmware as I was building it. Once each half was flashed, I had about a month of not flashing them as bit-by-bit I finished the build. (Note: I have never flashed both halves when they were connected.) I continued building and finally had them complete and connected both halves for the first time in a long time, but did not flash them. I proceeded to plug each half in at a time with the intention of flashing them with useful firmware other than the LED test firmware so that I may finally type with it. The two windows machines that I have tried on do not recognise the presence of either halves neither in QMK Toolbox nor in Device Manager. I am not getting the chimes as you would usually get when plugging or unplugging a USB device, and the reset button hasn't made made a difference either. Also, interestingly, if a Helix module is plugged in, it receives power and the OLED and LED presets work and I can cycle through them as expected, however this continues even when my windows machines are asleep or even shut down but still powered ! (I noted that this does not happen if the computer had not been booted but is shut down and powered) This behavior is similar to the LED's on my motherboard which stay on when the machine is shut down etc.
I have tried communicating with the pro micro using Arduino IDE but it was still undetectable and I didn't have any new ideas.
Someone mentioned "IPS programming to get the bootloader" but I'm not sure where to start with this.
Sidenote: I should mention that when the halves are connected, there is a slight difference in the lighting/hue/colors of LED's between the halves for LED presets apart from a few.

It is rather frustrating not being able to communicate with the pro micro's even though I was once able to...

Anyone who can help with this problem is much appreciated.

benomite, 2021-02-21:
Hi @Gazza2000 I think I am having a similar issue, did you manage to get your pro micros finally recognized by windows?

Closed 2020-05-21.

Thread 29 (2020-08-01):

Simultaneous backlighting and underglow?

Mandydeth, 2020-08-01:
More of a preemptive question than an issue: I'm currently in the process of assembling my Helix and have followed a few guides. Is it correct to assume that I can only enable backlighting _OR_ underglow, but not do both simultaneously? I know the Corne has the ability to do both, I was not sure if it was similar in that regard.

mtei, 2020-08-01:
That's right. It's just one of those things.

Closed 2020-08-14.

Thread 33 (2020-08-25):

Right side does not work

vbchekhov, 2020-08-25:
Hello, I collected everything, I asked for it, but the right side does not work, if I change the cable in places, the left side does not work. How do I fix the problem? I ran the firmware on both sides.

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

qmk setting
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

MakotoKurauchi, 2020-08-25:
Try these

Replace TRRS cable.
Check the soldering of the TRRS jack.
Check ProMicro soldering.

vbchekhov, 2020-08-25:
_Replace TRRS cable._ Done, 100% worked.
soldering
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

vbchekhov, 2020-08-25:
TRPC cable needs mono or stereo? Could it be too long?

MakotoKurauchi, 2020-08-25:
It looks like it's shorted out here
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

MakotoKurauchi, 2020-08-25:
This is also suspicious
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

vbchekhov, 2020-08-25:
Yep, fixed all the problems and it worked!

Closed 2020-08-25.

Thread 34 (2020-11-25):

Suggestion to add controller location to build guide

Adam-Edry, 2020-11-25:
The controller has two columns you can insert the pins into and it is not symmetrical between the two halves so I suggest an additional explanation:
The pins should go into the columns outlined by the silk on the top side of the board. If you are not sure you can match the labels on the board with the labels on the controller.

Best would be to have a picture showing the marking right before the controller part of the guide.

This was the only major issue I had when following the guide which required me to turn for help elsewhere

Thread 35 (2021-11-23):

Question regarding M2 standoffs

mhughes, 2021-11-23:
Guide calls for m2 7mm standoffs for mx switches.   I'm measuring 6mm when assembled.  Is it possible to switch to 6mm standoffs? thanks

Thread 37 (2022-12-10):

Material thickness not specified in build guide

adiron, 2022-12-10:
Hello there.

I'd like to build a Helix and order lasercut plates locally. However I do not know what the required thickness is. I'm assuming that the build has some thickness in mind as it recommends certain heights of standoffs.

Also, should a recommendation be made in the guide itself?

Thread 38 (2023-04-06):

Only left side works, unless powering right side

Thundernerd, 2023-04-06:
The problem I'm running in to is that if I power the left side then only the left side works, but if I power the right side then both sides work but the keymap is (understandably) flipped. Is there anything I need to do to fix this?

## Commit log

2018-01-27 Add all files
    [helix-B.Mask.gbr, helix-B.SilkS.gbr, helix-Edge.Cuts.gbr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]
2018-01-31 Add photo and LED value.
2018-02-07 説明が逆転しているので修正
2018-04-29 fix GFM syntax
    "brew tap osx-cross/avr"が表示されていませんでした。
2018-09-11 rename garber to gerber in PCB directory
    [helix-B.Mask.gbr, helix-B.SilkS.gbr, helix-Edge.Cuts.gbr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]
2020-03-06 Add info about choc low profile and SMD diodes
